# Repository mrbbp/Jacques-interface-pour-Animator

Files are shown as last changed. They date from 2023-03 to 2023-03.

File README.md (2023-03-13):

# Jacques® : interface pour Animator®

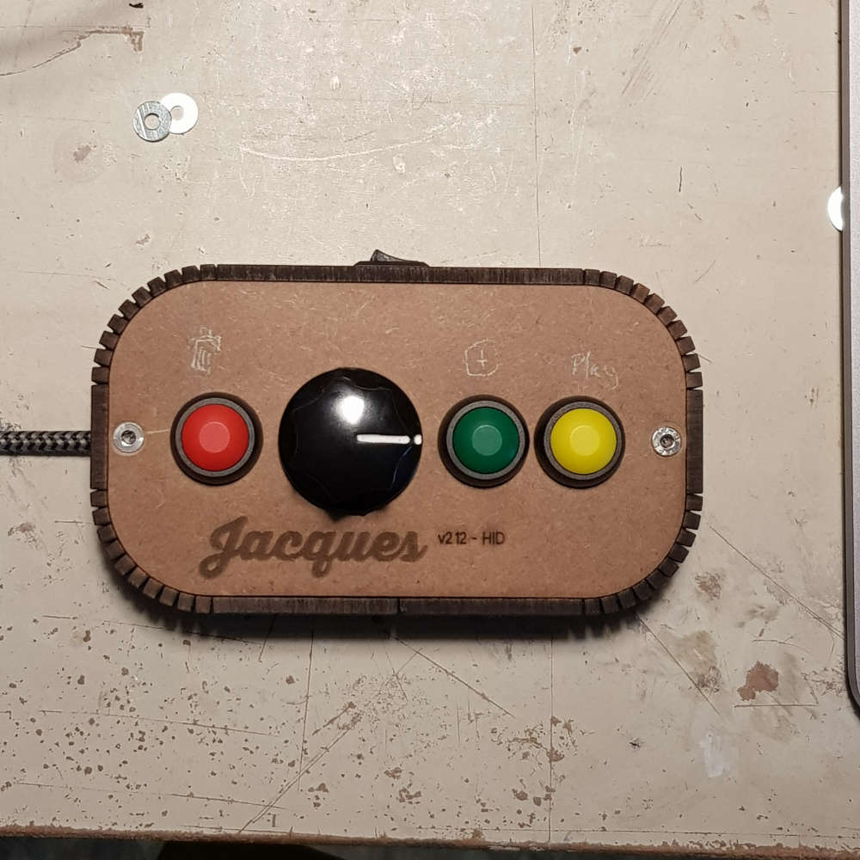
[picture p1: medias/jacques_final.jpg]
boitier terminé


Animator peut se compléter avec un petit boitier, une interface physique (tangible).
Le boitier comprend 3 boutons et un encodeur rotatif.  
Je disposais d'un lot de boutons colorés, j'en ai profité pour les intégrer au montage.
Le boitier est alimenté et communique via le cable usb-c.  
Il envoie des équivalents claviers pour chaque type d'opération. Et permet donc de simplifier certaines manipulations.

Une version spéciale d'Animator, estampillée v9, permet de tenir compte de nouveaux raccourcis claviers. Son usage sans le boitier est légèrement différent.  

Dans la **version 8**, la flèche de droite permet de se déplacer "en avant" dans l'animation et de rajouter une image lorsque l'on est à la dernière. Pour éviter l'ajout intempestifs d'images avec l'encodeur rotatif. Le comportement a été modifié.   

Dans la **version 9**, les flèches permettent uniquement le déplacement dans l'animation (l'encodeur envoie des équivalents clavier de flèches).  
Lorsqu'on atteint les bords de l'animation, un fond blanc apparaît brièvement.  
Pour ajouter une image, il faut appuyer sur le bouton vert (sur "ENTRÉE" au clavier), une image est ajoutée après l'image en cours et devient l'image en cours.  
Pour supprimer une image, il faut utiliser le bouton rouge (sur "BACKSPACE" au clavier) qui est placé de l'autre coté de l'encodeur. On supprime l'image encours.  
Le bouton Jaune ("barre d'espace" au clavier), quand à lui, permet la lecture/pause de l'animation.

Techniquement la boite contient un micro-contrôleur RP2040, codé en circuitPython.   
L'usb, le REPL et le midi ont été désactivés, pour simplifier l'usage du boitier (en évitant l'apparition du device sur la chaine usb ou midi).  

Un bouton "boot-code" (sur le côté opposé au cable) permet lorsqu'il est appuyé, au branchement à l'ordinateur, de réactiver les fonctions REPL et usb pour la mise à jour du code.  

Le boitier envoie des équivalents claviers, pour éviter de parasiter le comportement de l'ordinateur, si ce n'est pas Animator qui est au premier plan, un interrupteur (en haut sur la photo) permet de bloquer l'envoie des touches clavier (ça évite de le débrancher sans cesse).

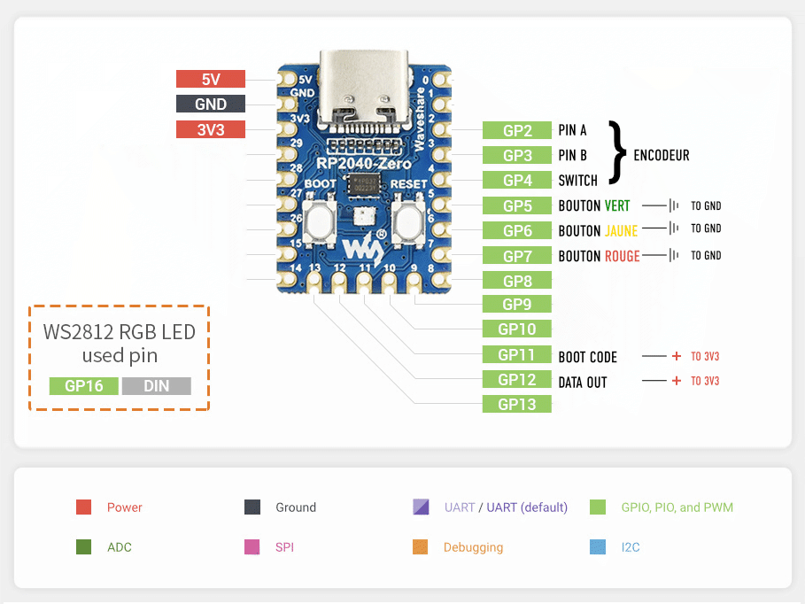
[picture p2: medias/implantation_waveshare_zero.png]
cablage de la carte


Les boutons sont connectés aux entrées du µc et mis à la terre.  
L'interrupteur et le bouton **bootcode**, sont connectés à  la pin **3V3** du µc plutôt que le **GND** (aucune raison particulière, une reprise de code existant sans harmonisation)

Le dossier _**lasercut**_ contient les fichiers de découpe laser du boitier (en laserworks, dxf et pdf). La boîte à été réalisée grâce au plugin de générateur de boites[^1] pour Inskape, de Thierry, du fablab de Lannion (grand merci pour ce fabuleux plugin fort utile).

Le dossier circuitpython, contient le code pour un **RP2040 pico zero** de _Waveshare_ (petit gabarit, pas cher). Il s'adaptera facilement à tout autre pico (il suffit de faire correspondre les noms des io et les numéros).

La Police de caractère du nom, est la **Thirsty Soft**[^2] Black de Yellow Design Studio. La police Single Line est la **SLF Architect**[^3].

[^1]: le plugin [générateur de boites](https://wiki.fablab-lannion.org/index.php?title=Generateur_de_boites)
[^2]: [Yellow Design Studio](https://yellowdesignstudio.com/collections/thirsty-soft)
[^3]: chez [Singlelinefonts](https://www.singlelinefonts.com/products/slf-architect-for-inkscape-and-fontlab-pad)

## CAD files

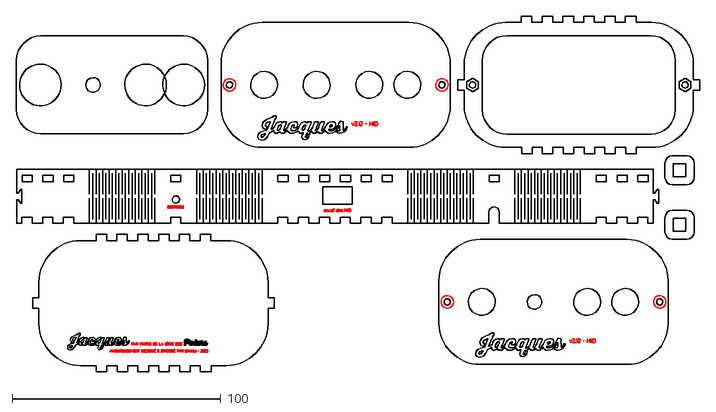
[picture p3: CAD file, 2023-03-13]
lasercut/jacques 2.12.dxf
327.7 x 170.6

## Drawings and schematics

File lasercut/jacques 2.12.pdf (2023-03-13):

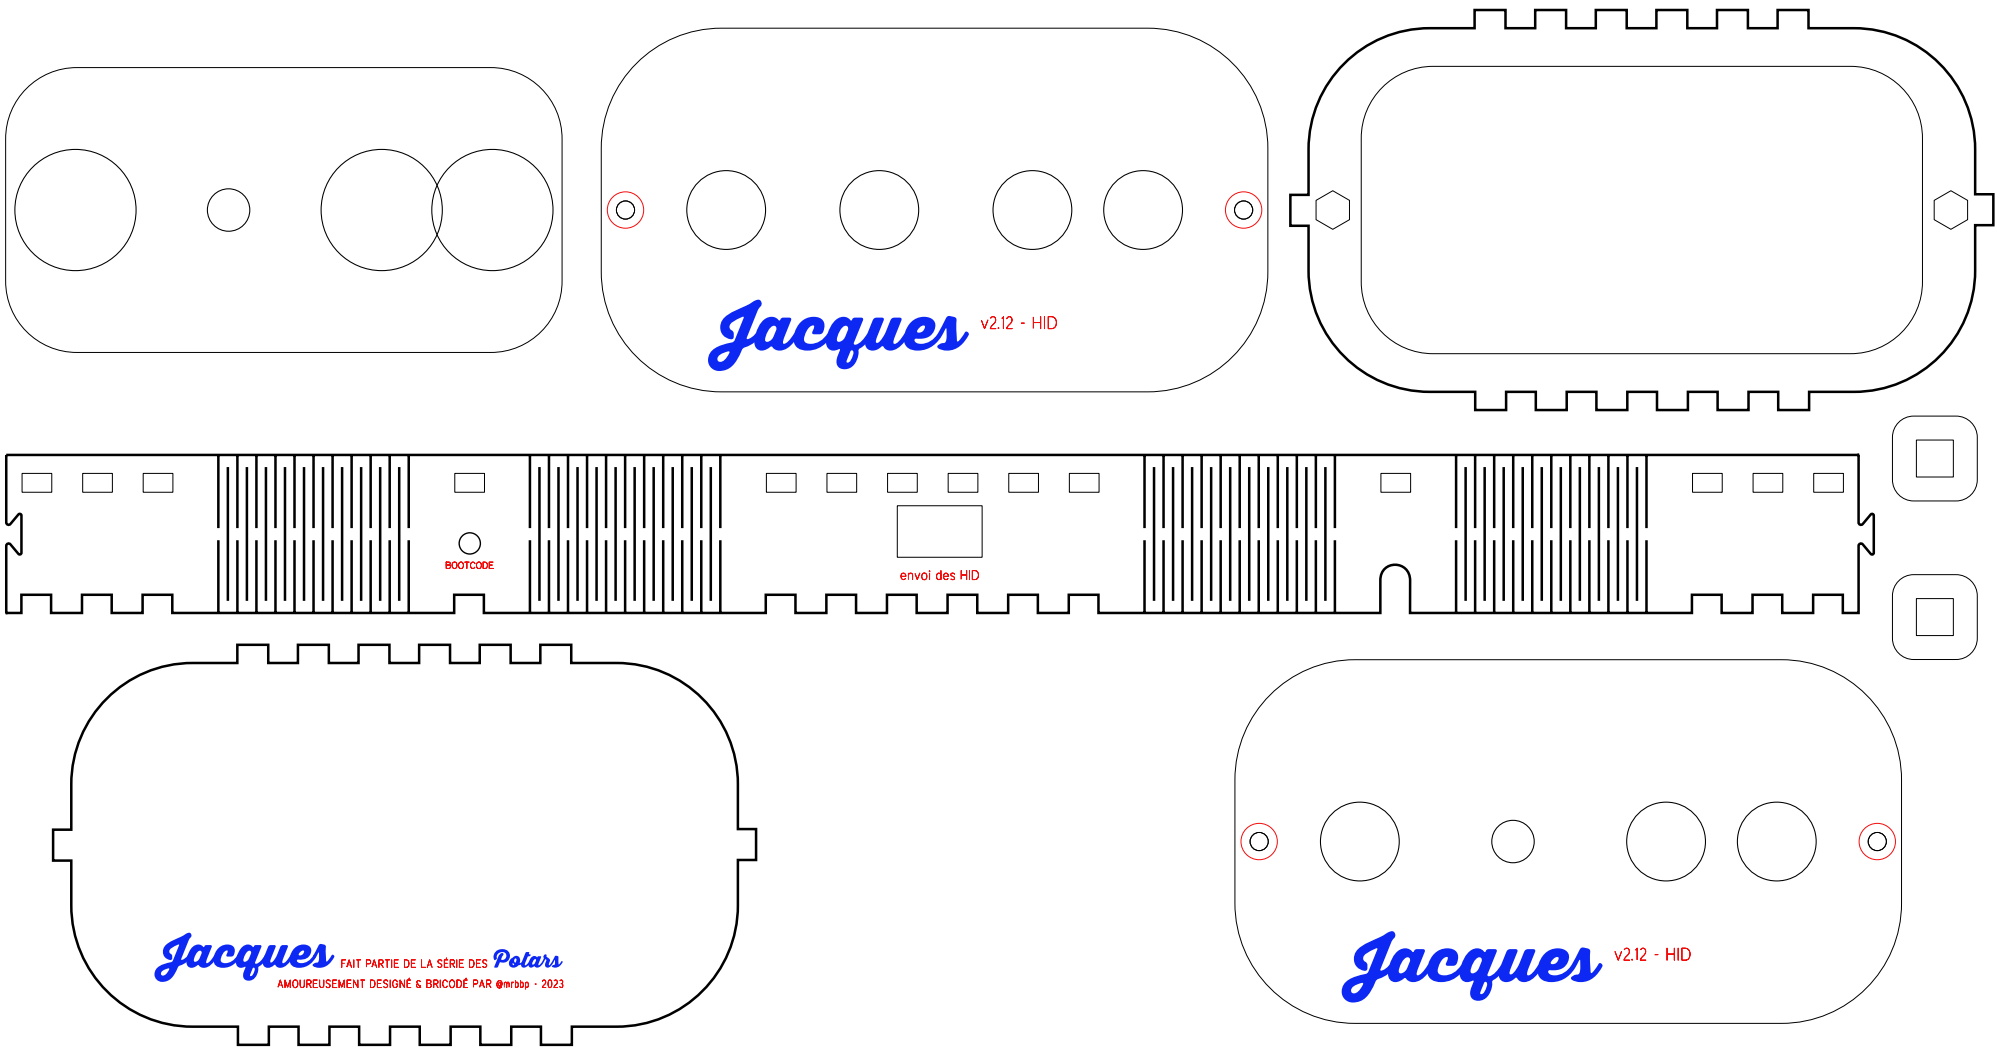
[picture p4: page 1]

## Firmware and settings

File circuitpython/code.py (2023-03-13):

# code base: ©2018 Kattni Rembor for Adafruit Industries
#
# complete code @mrbbp 2303
#
# SPDX-License-Identifier: MIT

import time
# lib de l'encodeur rotatif
import rotaryio
# gestion de la config de la carte
import board
# gestion des IO num.
import digitalio
# gestion de l'usb_HID (transformer la carte en device HID)
import usb_hid

# import lib des raccourcis clavier
from adafruit_hid.keyboard import Keyboard
from adafruit_hid.keycode_mac_fr import Keycode
# import lib de la led onboard
import neopixel

boutonEncodeur = digitalio.DigitalInOut(board.GP4)
boutonEncodeur.direction = digitalio.Direction.INPUT
boutonEncodeur.pull = digitalio.Pull.UP

boutonRouge = digitalio.DigitalInOut(board.GP7)
boutonRouge.direction = digitalio.Direction.INPUT
boutonRouge.pull = digitalio.Pull.UP

boutonJaune = digitalio.DigitalInOut(board.GP6)
boutonJaune.direction = digitalio.Direction.INPUT
boutonJaune.pull = digitalio.Pull.UP

boutonVert = digitalio.DigitalInOut(board.GP5)
boutonVert.direction = digitalio.Direction.INPUT
boutonVert.pull = digitalio.Pull.UP

boutonData = digitalio.DigitalInOut(board.GP12)
boutonData.direction = digitalio.Direction.INPUT
boutonData.pull = digitalio.Pull.DOWN

# gestion de la led

led = neopixel.NeoPixel(board.NEOPIXEL, 1)
# éteint la led
led.brightness = 0

# déclaration de l'encodeur
encoder = rotaryio.IncrementalEncoder(board.GP2, board.GP3)

# déclaration du clavier
keyboard = Keyboard(usb_hid.devices)

# état des boutons
boutonEncodeur_state = None
boutonRouge_state = None
boutonVert_state = None
boutonJaune_state = None
last_position = encoder.position


while True:
    current_position = encoder.position
    position_change = current_position - last_position
    if boutonData.value:
        if position_change > 0:
            keyboard.press(Keycode.RIGHT_ARROW)
            led.brightness = .3
            led[0] = (255, 0, 0)
            time.sleep(.04)
            keyboard.release(Keycode.RIGHT_ARROW)
            led.brightness = 0
            print("->", current_position)
        elif position_change < 0:
            keyboard.press(Keycode.LEFT_ARROW)
            led.brightness = .3
            led[0] = (0, 0, 255)
            time.sleep(.04)
            keyboard.release_all()
            led.brightness = 0
            print("<-", current_position)
        last_position = current_position
        if not boutonEncodeur.value and boutonEncodeur_state is None:
            boutonEncodeur_state = "pressed"
        if boutonEncodeur.value and boutonEncodeur_state == "pressed":
            print("boutonEncodeur pressed.")
            # led allumée verte
            led.brightness = .3
            led[0] = (0, 255, 0)
            # envoie le HID
            keyboard.press(Keycode.ENTER)
            keyboard.release_all()
            boutonEncodeur_state = None
            # 1/25 sec et éteint la led
            time.sleep(0.04)
            led.brightness = 0
        if not boutonJaune.value and boutonJaune_state is None:
            boutonJaune_state = "pressed"
        if not boutonVert.value and boutonVert_state is None:
            boutonVert_state = "pressed"
        if not boutonRouge.value and boutonRouge_state is None:
            boutonRouge_state = "pressed"
        if boutonVert.value and boutonVert_state == "pressed":
            print("boutonVert pressed.")
            # led allumée verte
            led.brightness = .3
            led[0] = (0, 255, 0)
            # envoie le HID
            keyboard.press(Keycode.ENTER)
            keyboard.release_all()
            boutonVert_state = None
            # 1/25 sec et éteint la led
            time.sleep(0.04)
            led.brightness = 0
        if boutonJaune.value and boutonJaune_state == "pressed":
            print("boutonJaune pressed.")
            # led allumée jaune
            led.brightness = .3
            led[0] = (255, 255, 0)
            # envoie le HID
            keyboard.press(Keycode.SPACEBAR)
            keyboard.release_all()
            boutonJaune_state = None
            # 1/25 sec et éteint la led
            time.sleep(0.04)
            led.brightness = 0
        if boutonRouge.value and boutonRouge_state == "pressed":
            print("boutonRouge pressed.")
            # led allumée rouge
            led.brightness = .3
            led[0] = (255, 0, 0)
            # envoie le HID (B)
            # keyboard.press(0x05) touche B
            keyboard.press(Keycode.BACKSPACE)
            keyboard.release_all()
            boutonRouge_state = None
            # 1/25 sec et éteint la led
            time.sleep(0.04)
            led.brightness = 0

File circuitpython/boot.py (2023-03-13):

# This example is for a Circuit Playground,
# or any board with buttons that are connected to +V when pressed.
# désactive l'usb, le REPL et le midi sur la carte
# il faut un bouton connecté au + sur le GP4
# lorsque le bouton est appuyé, la carte fait apparaitre de device usb et l'interface de prog


import storage, usb_cdc
import board, digitalio

# On the Circuit Playground, pressing an on-board button
# connects the button to +V and GP4.
button = digitalio.DigitalInOut(board.GP11)
button.direction = digitalio.Direction.INPUT
button.pull = digitalio.Pull.DOWN

# Disable devices only if button is not pressed.
if not button.value:
  storage.disable_usb_drive()
  usb_midi.disable()
  usb_cdc.disable()
